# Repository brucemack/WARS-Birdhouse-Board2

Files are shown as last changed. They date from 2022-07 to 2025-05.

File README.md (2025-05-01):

Connector J1
============

Right Column
* 1: 3.3V out, used for onboard SX1276 module, but could also be used to power MCU.
* 3: Raw panel input, not used for anything on board *except* panel sense.
* 5: Raw panel input, could be used for charge controller IN+.
* 7: 4-6V supply in, could be taken from charge controller OUT+.
* 9: Panel sense out, could be sent to ADC for monitoring.
* 11: 4-6V supply sense out, could bne sent to ADC for monitoring.
* 13: GND (i.e. panel ground)
* 15: GND (i.e. charge controller OUT-)

Left Column
* 2: Radio interrupt out
* 4: Radio reset in
* 6: Radio SPI CS in
* 8: Radio SPI SCK in 
* 10: Radio SPI MOSI in
* 12: Radio SPI MISO out 
* 14: GND
* 16: GND

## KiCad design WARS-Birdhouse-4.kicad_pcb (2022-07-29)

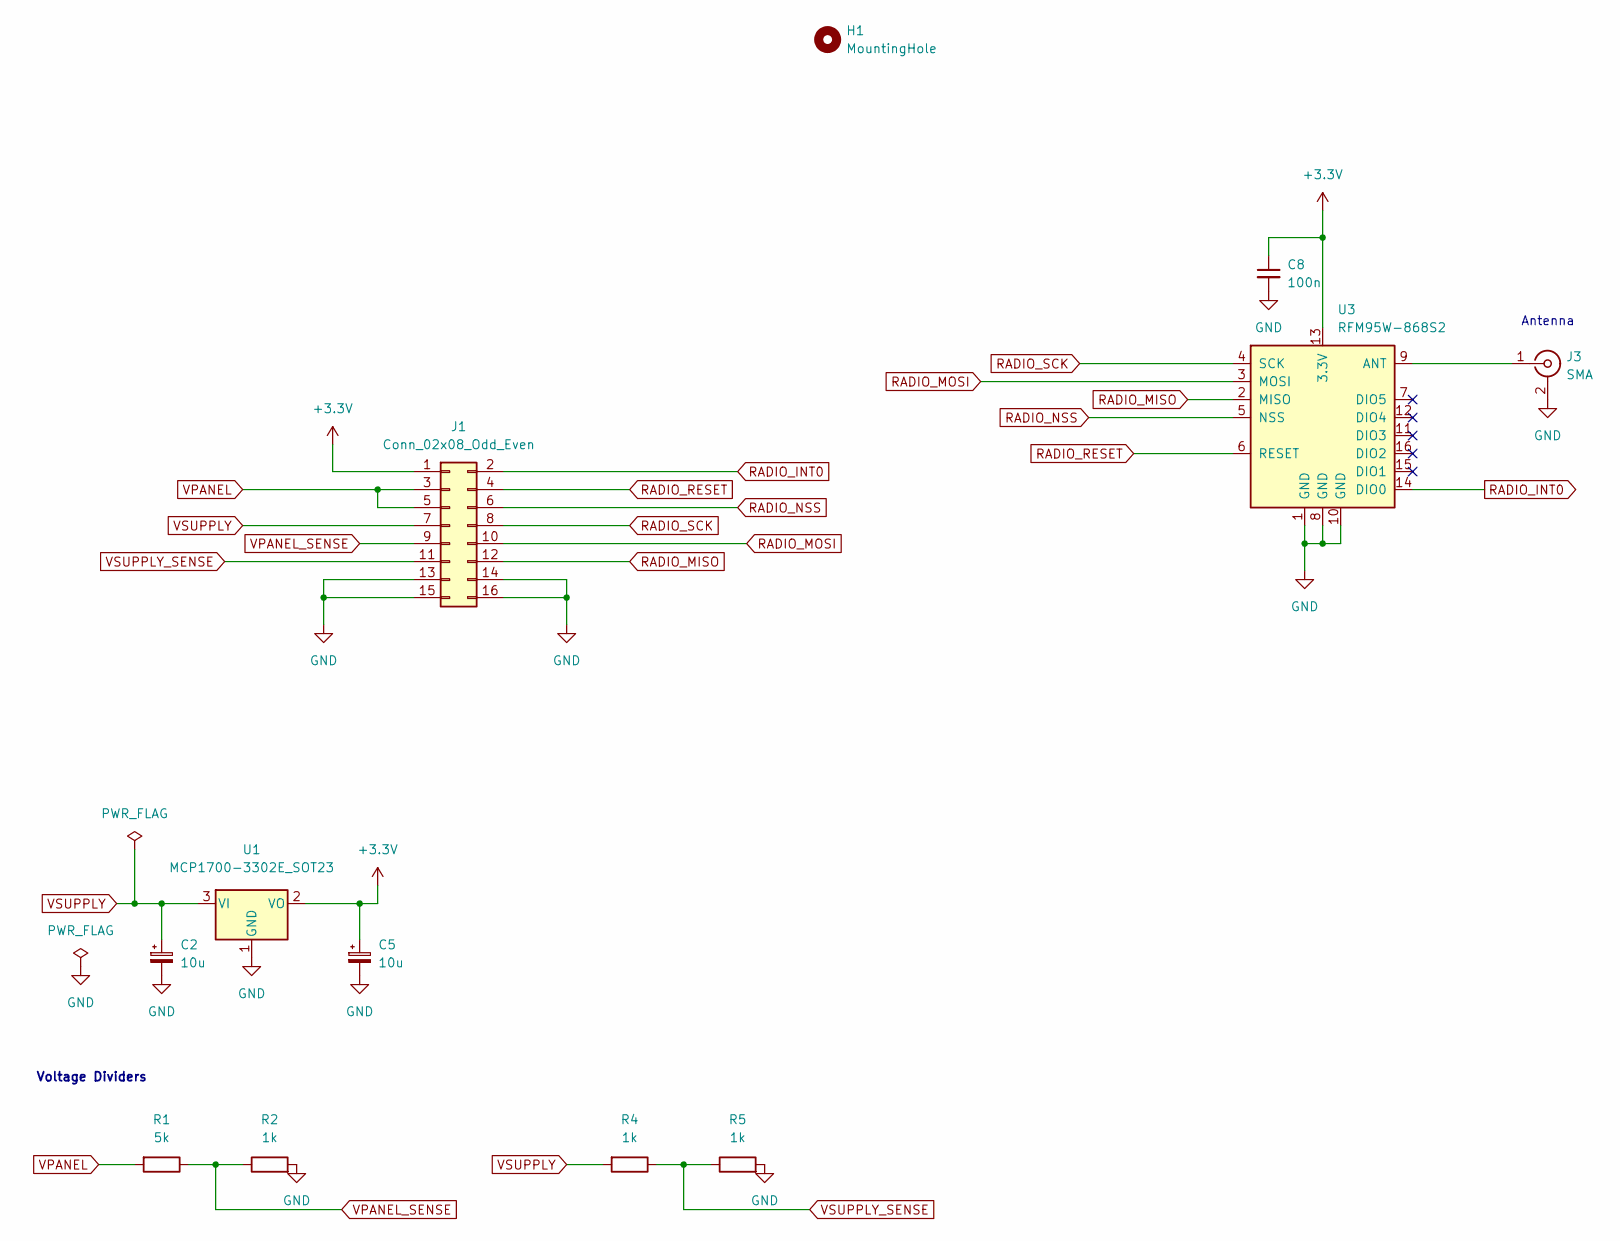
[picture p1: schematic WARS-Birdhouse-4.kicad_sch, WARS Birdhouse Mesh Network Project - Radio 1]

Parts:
C2, C5: 10u; CP_Elec_4x5.4
C8: 100n; C_0805_2012Metric_Pad1.18x1.45mm_HandSolder
H1: MountingHole; MountingHole_4mm
J1: Conn_02x08_Odd_Even; PinSocket_2x08_P2.54mm_Vertical
J3: SMA; SMA_Amphenol_132134_Vertical
R1: 5k; R_0805_2012Metric_Pad1.20x1.40mm_HandSolder
R2, R4, R5: 1k; R_0805_2012Metric_Pad1.20x1.40mm_HandSolder
U1: MCP1700-3302E_SOT23; SOT-23
U3: RFM95W-868S2; HOPERF_RFM9XW_SMD

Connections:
+3V3: C5.1, C8.1, J1.1, U1.2 (VO), U3.13 (3.3V)
GND: C2.2, C5.2, C8.2, J1.13, J1.14, J1.15, J1.16, J3.2 (Ext), R2.2, R5.2, U1.1 (GND), U3.1 (GND), U3.8 (GND), U3.10 (GND)
unnamed: J3.1 (In), U3.9 (ANT)
RADIO_INT0: J1.2, U3.14 (DIO0)
RADIO_MISO: J1.12, U3.2 (MISO)
RADIO_MOSI: J1.10, U3.3 (MOSI)
RADIO_NSS: J1.6, U3.5 (NSS)
RADIO_RESET: J1.4, U3.6 (RESET)
RADIO_SCK: J1.8, U3.4 (SCK)
VPANEL: J1.3, J1.5, R1.2
VPANEL_SENSE: J1.9, R1.1, R2.1
VSUPPLY: C2.1, J1.7, R4.2, U1.3 (VI)
VSUPPLY_SENSE: J1.11, R4.1, R5.1

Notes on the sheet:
Antenna
Voltage Dividers

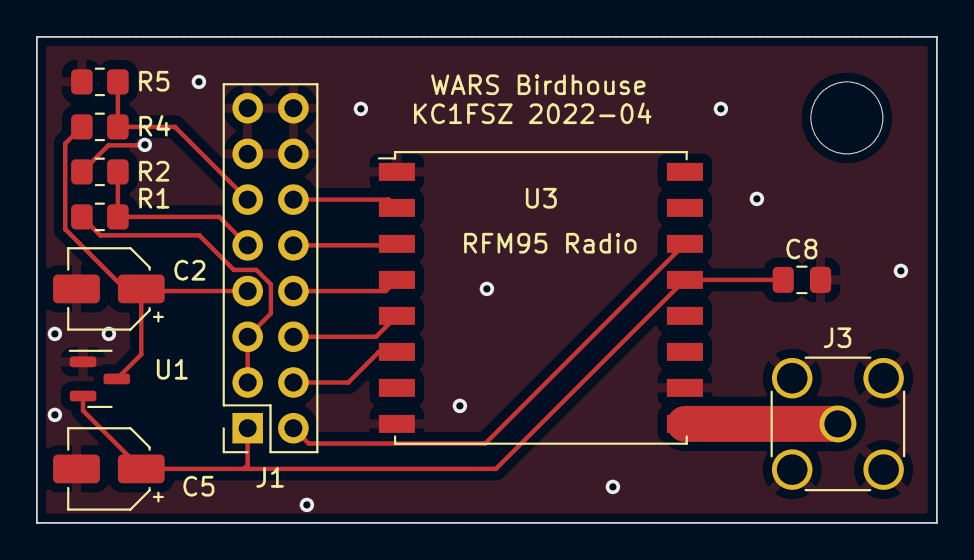
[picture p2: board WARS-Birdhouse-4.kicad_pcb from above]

Board: 2 copper layers, 50.0 x 27.0 mm, 12 parts (0 on the bottom side), 13 nets.

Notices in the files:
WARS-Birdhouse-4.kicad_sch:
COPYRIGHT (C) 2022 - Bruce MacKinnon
